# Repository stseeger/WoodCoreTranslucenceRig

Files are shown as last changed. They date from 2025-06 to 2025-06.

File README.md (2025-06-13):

WoodCoreTranslucenceRig
===========

The distinction between sapwood and heartwood is important for the correct upscaling of point based measurements of sap flux densities (obtained from sapflow probes) to the tree level. In some cases, there are no obvious visual differences between sapwood and heartwood. In such cases, translucence may be an option to distinguish the hydraulically active sapwood from the heartwood. If you are lucky, natural light conditions are just fine for that method, but sometimes it can be necessary to get a better control of light for the translucence method.

In this repository I provide:
* 3D printable parts for a translucence rig (suited for wood core samples with ø = 5.15 mm )
* Firmware to use an Arduino to control an LED strip placed within the translucence rig
 
The current version of the translucence rig features slits at 10 mm intervals that make it possible to use a scalpel to slice the wood core while it is within the rig.

## About

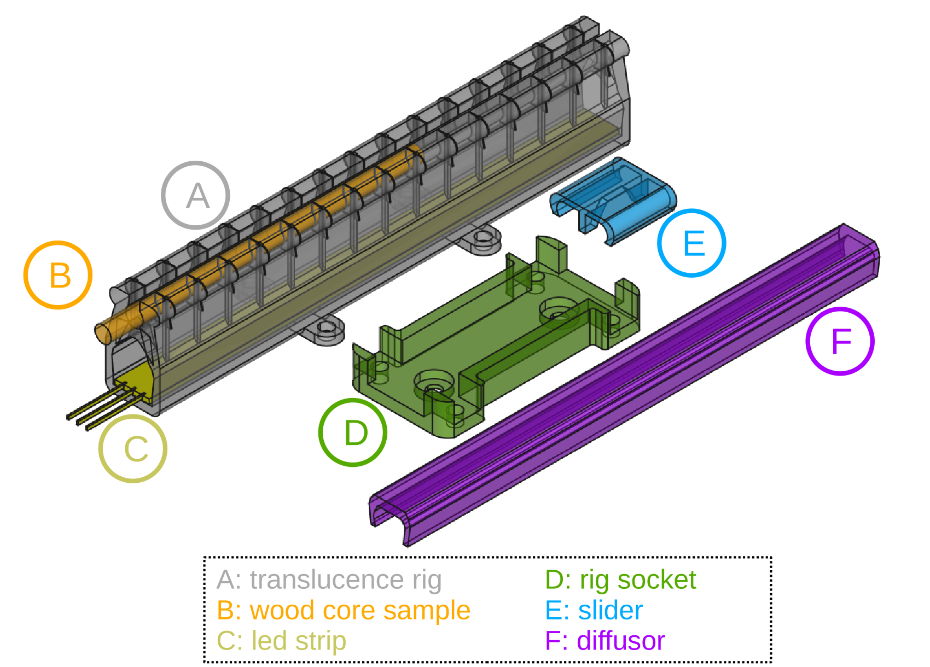
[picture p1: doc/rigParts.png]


Print the following parts with a black, non-reflecting  material:  
[A: translucenceRig-rig.stl](Hardware/translucenceRig-rig.stl)  
[D: translucenceRig-socket.stl](Hardware/translucenceRig-socket.stl) (optional)  
[E: translucenceRig-slider.stl](Hardware/translucenceRig-slider.stl)  

Print the following part with a transparent material with a matte surface finnish:  
[E: translucenceRig-diffusor.stl](Hardware/translucenceRig-diffusor.stl)  

Aquire an WS2812B (or similar) LED strip with 60 LEDs/m (a 20 cm piece should suffice) and place it at the bottom of the rig.
[Connect the LED-strip to an Arduino Uno](doc/wiring_LED_to_Arduino.JPG) programmed with the [provided firmware](Firmware/translucenceRig/translucenceRig.ino).  

Connect the Arduino to a computer and open the Serial Monitor of the Arduino IDE to adjust the number of active LEDs and their brightness. If you are able to minimize the ambient light around the rig (e.g. by placing it in a dark box), you will get better results at lower brightness values of the LED strip.  

Aquire a fresh wood core (B) with an 5.15 mm increment borer and slide it into the rig.  Before fully sliding the core into the rig, you should find the orientation with the maximum translucence. Afterwards, you can use the slider (E) to move the core sample it within the rig.  

Identify the sapwood by translucence, take a photograph and use a scalpel to slice the wood core into sapwood and heartwood through one of the slits within the rig. Use the slider to push all parts of the wood core out of the rig.

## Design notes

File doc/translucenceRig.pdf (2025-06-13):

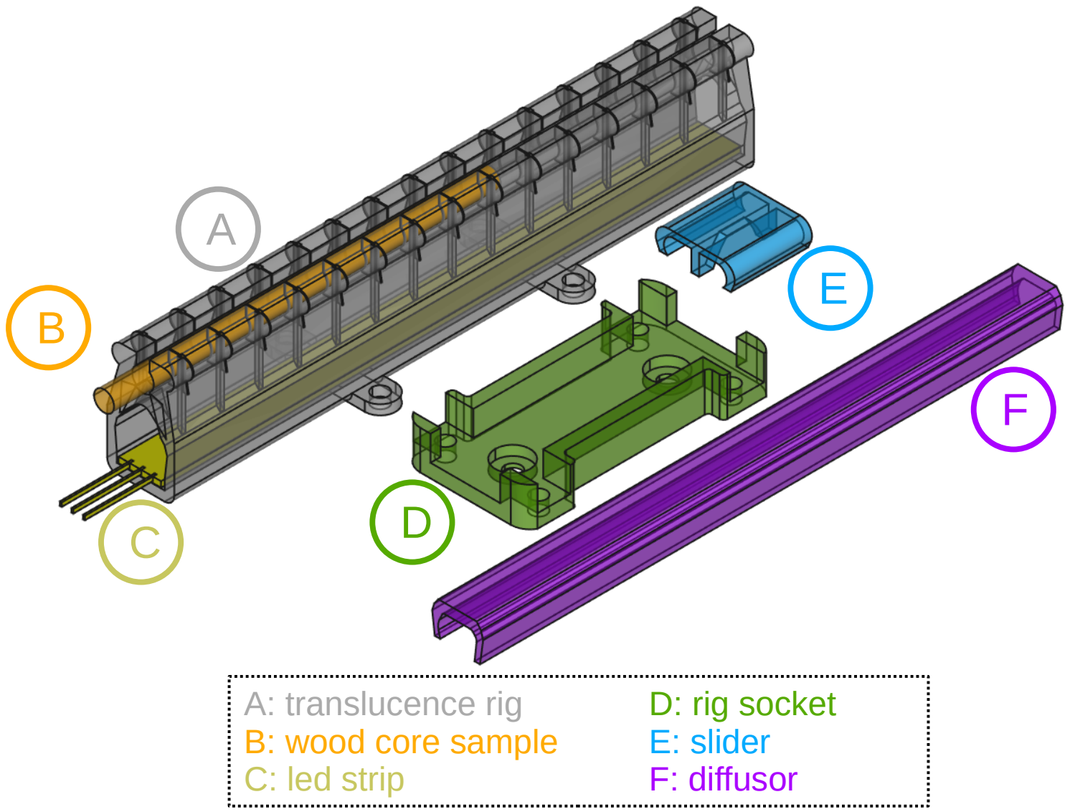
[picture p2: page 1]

A

B
F

E

D

A: translucence rig | D: rig socket
B: wood core sample | E: slider
C: led strip | F: diffusor

C

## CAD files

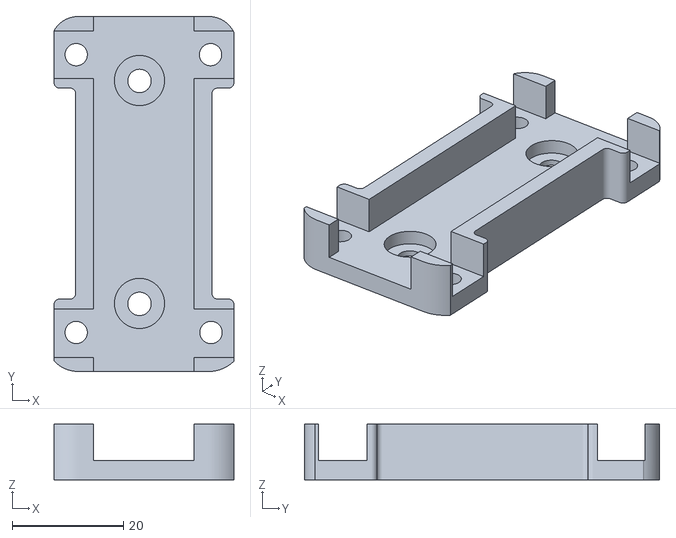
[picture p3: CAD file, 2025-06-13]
Hardware/translucenceRig-socket.stl
32.3 x 63.7 x 10.0

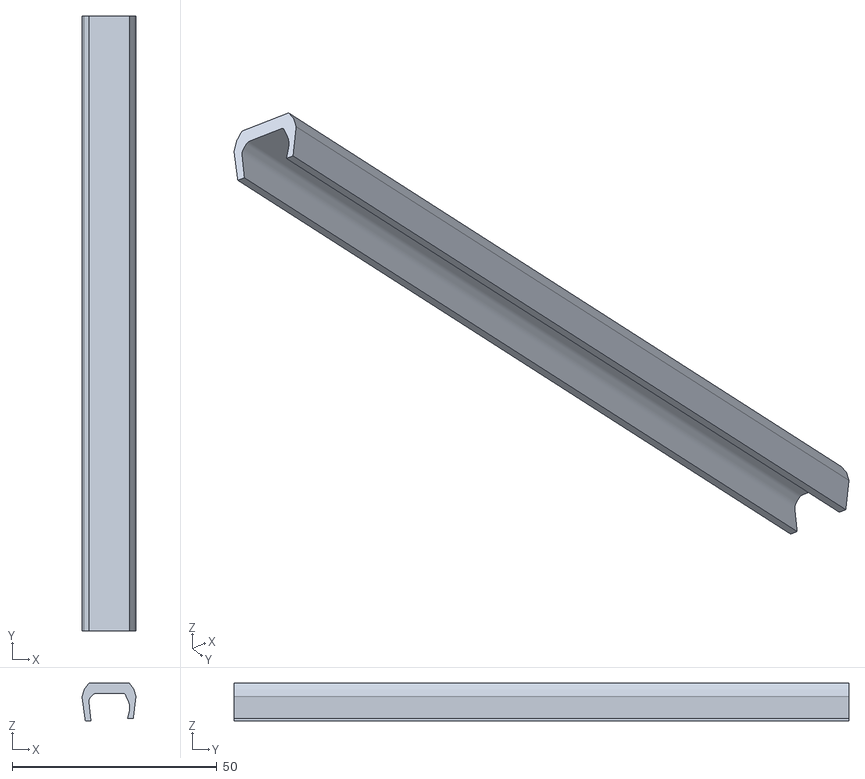
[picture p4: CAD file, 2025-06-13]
Hardware/translucenceRig-diffusor.stl
13.2 x 150.0 x 9.17

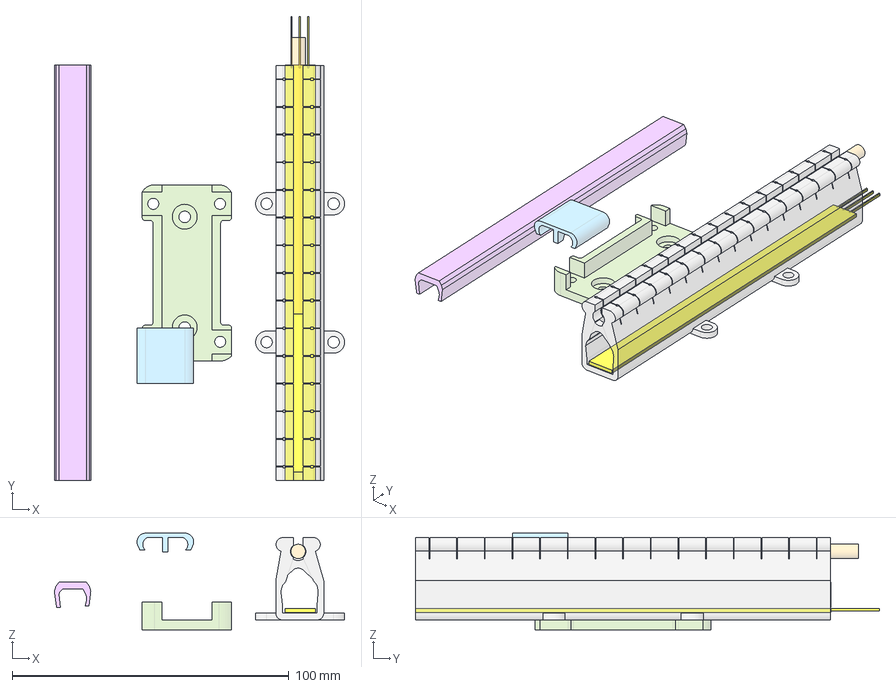
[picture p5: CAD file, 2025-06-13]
Hardware/translucenceRig.FCStd
104.9 x 167.7 x 34.9 mm
sampleDummy
ledStripDummy
rig
socket
slider
diffusor

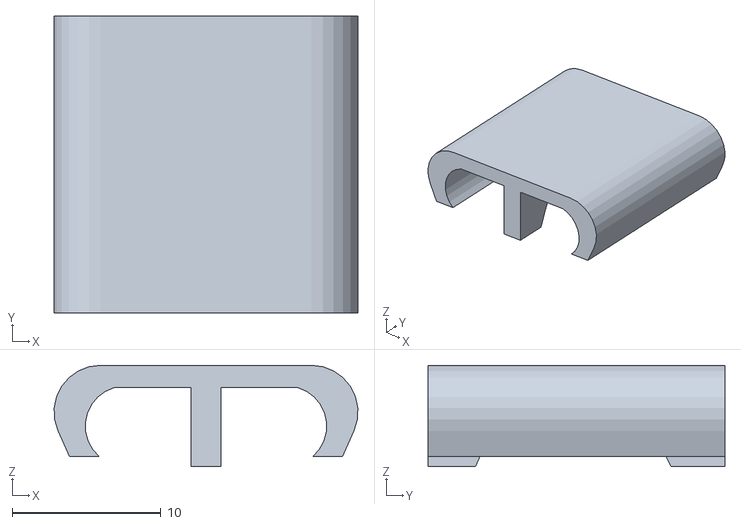
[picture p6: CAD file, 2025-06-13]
Hardware/translucenceRig-slider.stl
20.5 x 20.0 x 6.83

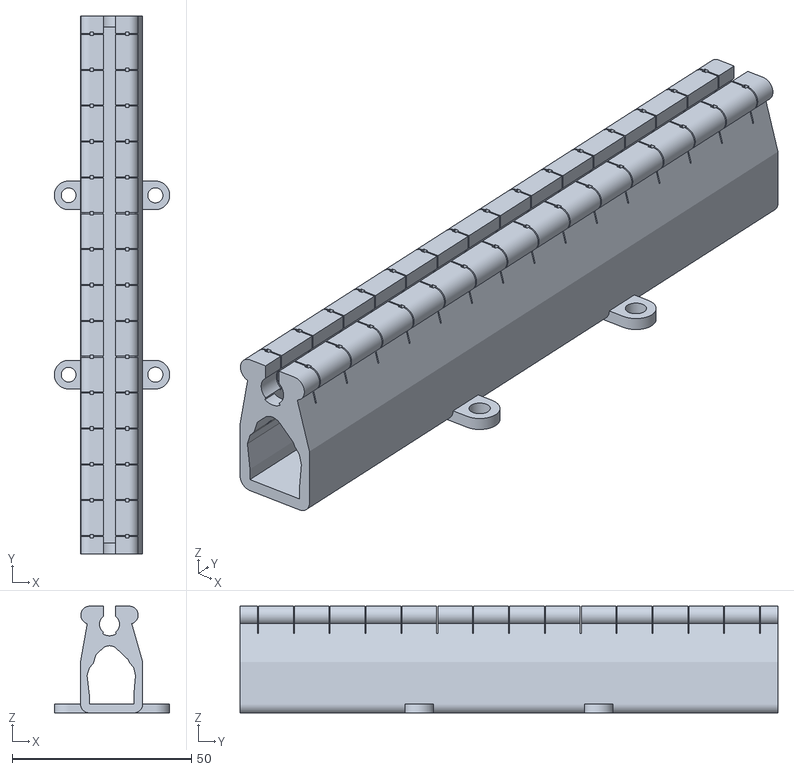
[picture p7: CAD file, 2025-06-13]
Hardware/translucenceRig-rig.stl
32.2 x 150.0 x 29.8

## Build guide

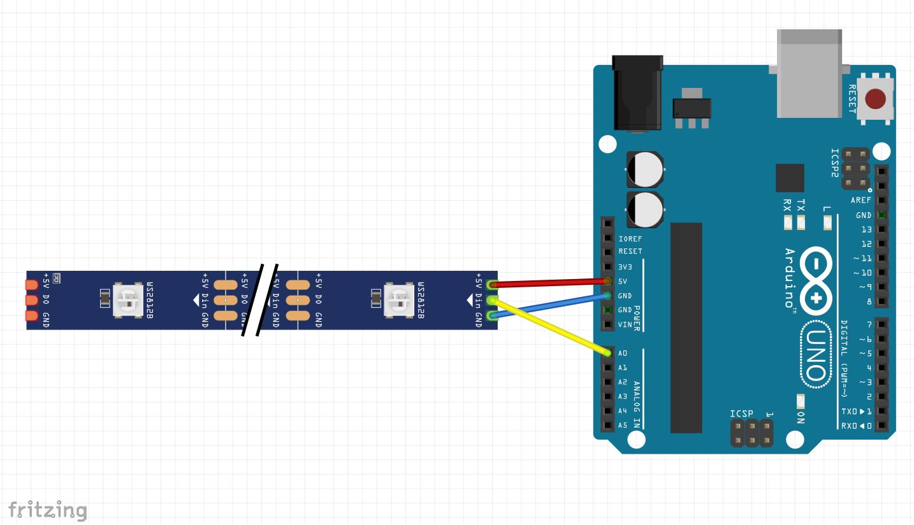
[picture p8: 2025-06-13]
doc/wiring_LED_to_Arduino.JPG

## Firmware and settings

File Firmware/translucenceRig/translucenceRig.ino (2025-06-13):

/***
https://github.com/stseeger/WoodCoreTranslucenceRig

This script is intended to control an WS2812b LED strip that is to be placed at
the bottom of the translucenceRig to inspect wood core samples.

The script provides a command line interface to adjust the settings while
the script is running. Once you have found suiting settings, I recommend to adjust
the default values defined in this script.

--------------------
Dependencies:
The FastLED library available through the Arduino Library manager or:
https://github.com/FastLED/FastLED

The CmdArduino library available through the Arduino library manager or:
https://github.com/freaklabs/cmdArduino

--------------------
Connections:
WS2812b -> Adruino
+5V     -> VIN (assuming the Arduino is powered via USB)
Din     -> A0
GND     -> GND

!!! ATTENTION !!!
With white light at the highest brighntess value (255) each LED is drawing around 60 mA.
This means, that 15 LEDs at full brightness already draw 900 mA, which is the maximum allowed
current draw from an USB3-Port (the limit for an USB2-port is already at 500 mA).
Please keep that in mind and make sure not to overcharge your USB port.
Luckiliy, running the LEDs at much lower brightness levels produces the same results when used in a 
dark environment.
***/

//SETTINGS
#define DATA_PIN A0 // change to any other pin if yu need A0 for something else

// How many LEDs in your strip?
#define NUM_LEDS 15

// define variables to store settings and define default values
int value=20;
int first=1;
int count = 10;
char color = 'w';


//import libraries
#include <FastLED.h>
#include <cmdArduino.h>

//define device info
#define DEVICE "translucenceRig"
#define VERSION "2.0"


// Define the array of leds
CRGB leds[NUM_LEDS];

//~~~~~~~~~ define functions ~~~~~~~~~~~~~~~~~~~~~~

void cmd_info(int arg_cnt, char **args){
  Serial.println("----------------------");
  Serial.print(DEVICE);  
  Serial.print(" v");
  Serial.println(VERSION);

  Serial.println("Overview of possible commands:");
  Serial.println("   (if no value is passed for n or c, the current value will be returned)");
  Serial.println("?        : print this overview of commands");
  Serial.println("count [n]: set how many LEDs should be lit");
  Serial.println("first [n]: set the first led that should be lit (1<=n<=NUMBER_OF_LEDS");
  Serial.println("value [n]: set how bright the LEDs should be lit (0<=n<=255)");  
  Serial.println("color [c]: set the color of all LEDS ('w'=white, 'r'=red, 'g'=green, 'b'=blue)");
  if(!arg_cnt)Serial.print(">>");
}

void cmd_setFirstLED(int arg_cnt, char **args){
  if(arg_cnt<2) Serial.println(first);
  else first = atoi(args[1]); 
}

void cmd_setLEDcount(int arg_cnt, char **args){
  if(arg_cnt<2) Serial.println(count);
  else count = atoi(args[1]); 
}

void cmd_setBrightness(int arg_cnt, char **args){
  if(arg_cnt<2) Serial.println(value);
  else value = atoi(args[1]);
}

void cmd_setColor(int arg_cnt, char **args){
  if(arg_cnt<2) Serial.println(color);
  else color = args[1][0];  
}


//~~~~~~~~~ setup ~~~~~~~~~~~~~~~~~~~~~~

void setup() { 
    FastLED.addLeds<NEOPIXEL, DATA_PIN>(leds, NUM_LEDS);  // GRB ordering is assumed
    FastLED.setBrightness(value);
    for(byte n=0; n < NUM_LEDS;n++) leds[n] = CRGB::Black;
    FastLED.show();
    
    // initialize command line interface
    cmd.begin(9600);
    // assign cmd commands
    /*
     * the first argument of cmdAdd is a command string,
     * the second argument is the function it will trigger
     */
    cmd.add("?", cmd_info);
    cmd.add("first", cmd_setFirstLED);
    cmd.add("count", cmd_setLEDcount);
    cmd.add("value", cmd_setBrightness);
    cmd.add("color", cmd_setColor);
    // inform the user how the device can be used
    cmd_info(0,NULL);
}


//~~~~~~~~~ main loop ~~~~~~~~~~~~~~~~~~~~~~
void loop() { 

  // check if a command was passed
  cmd.poll();

  //set color
  CRGB col = CRGB::White;
  if(color=='b') col=CRGB::Blue;
  if(color=='r') col=CRGB::Red;
  if(color=='g') col=CRGB::Green;

  // light as many LEDs as specified in count, starting at first
  for(byte n=1; n < NUM_LEDS;n++){    
    leds[n] = (n>=first & n < first+count) ? col : CRGB::Black;
  }
  
  //set brightness as specified by value
  FastLED.setBrightness(value);
  FastLED.show();
  delay(50);
}
